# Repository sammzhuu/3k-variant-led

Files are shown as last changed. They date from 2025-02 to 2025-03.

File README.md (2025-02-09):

# 3k-variant-led
 a rehash of my scrapped 6k build now with 3k and leds 

if you want to build this project yourself, here are some useful guides: 
https://docs.google.com/document/d/1xsjb1sf3pxFw8bXC4gNhWsFhWNOthMoyz6RiJc1UtVI/edit?tab=t.0
https://www.youtube.com/watch?v=Ov2vdJQmaAw
https://www.masterzen.fr/2020/05/03/designing-a-keyboard-part-1/
https://wiki.ai03.com/books/pcb-design/page/pcb-guide-part-1---preparations

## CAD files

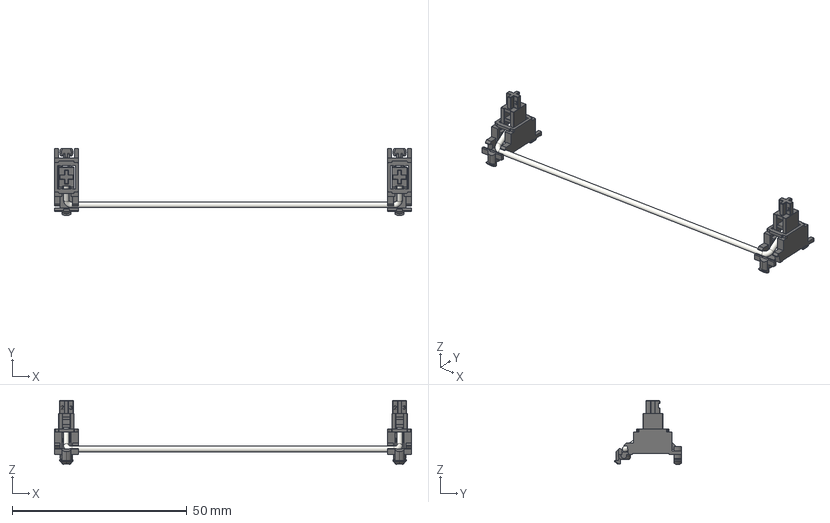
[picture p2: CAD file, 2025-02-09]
keyswitch-kicad-library/source_3d/Mounting_Keyboard_Stabilizer/Stabilizer_Cherry_MX_6u.FCStd
102.1 x 19.2 x 18.3 mm
Bar
Stabilizer_Key_
Stabilizer_Base_
Stabilizer_Key
Stabilizer_Base

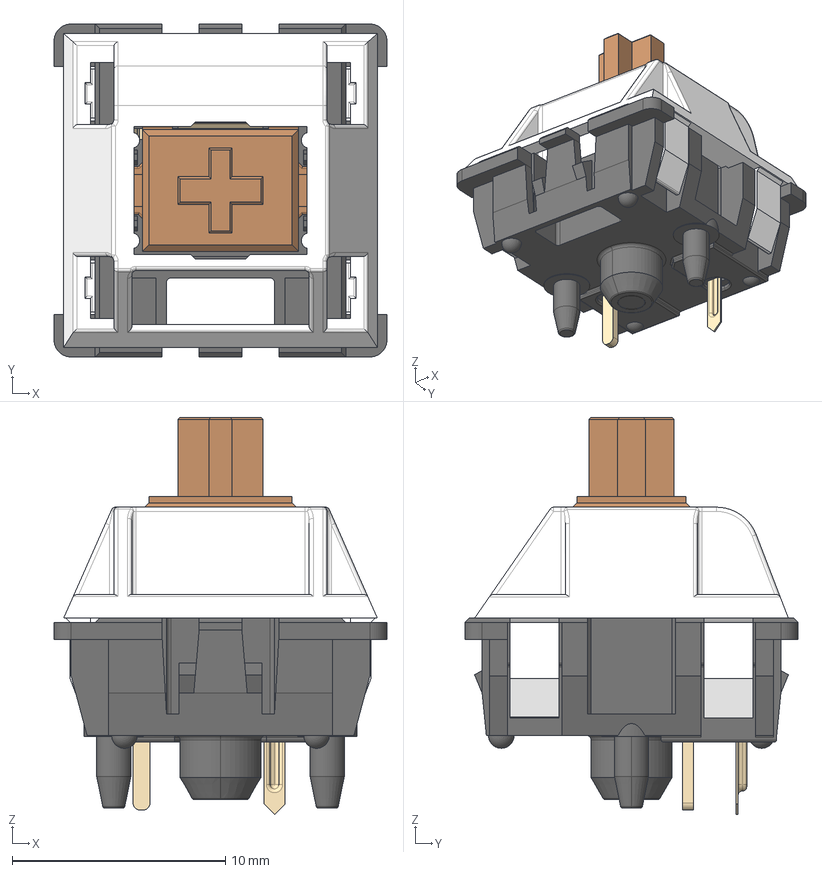
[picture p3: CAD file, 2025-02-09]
keyswitch-kicad-library/source_3d/Switch_Keyboard_Cherry_MX/SW_Cherry_MX_PCB.FCStd
15.6 x 15.6 x 18.6 mm
Lower_Housing
Upper_Housing
Stem
Pin_1
Pin_2
Spring
Clicker

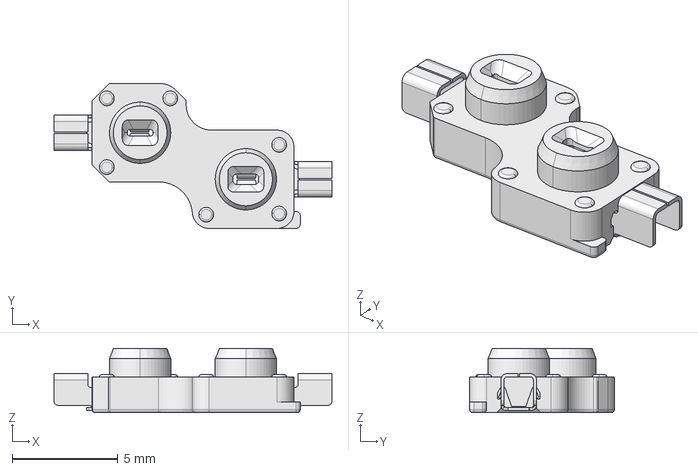
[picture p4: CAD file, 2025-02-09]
keyswitch-kicad-library/source_3d/Switch_Keyboard_Kailh/SW_Hotswap_Kailh_Choc_v1.FCStd
13.2 x 6.85 x 3.05 mm

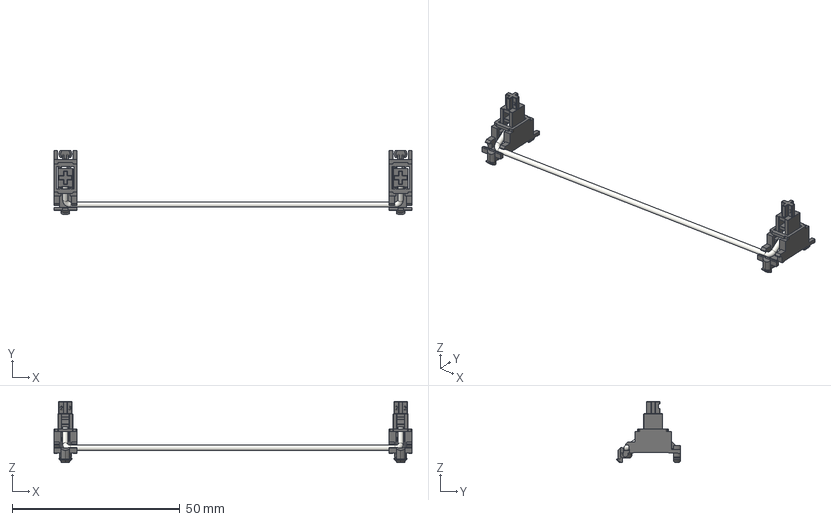
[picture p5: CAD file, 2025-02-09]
keyswitch-kicad-library/source_3d/Mounting_Keyboard_Stabilizer/Stabilizer_Cherry_MX_6.25u.FCStd
106.8 x 19.2 x 18.3 mm
Bar
Stabilizer_Key_
Stabilizer_Base_
Stabilizer_Key
Stabilizer_Base

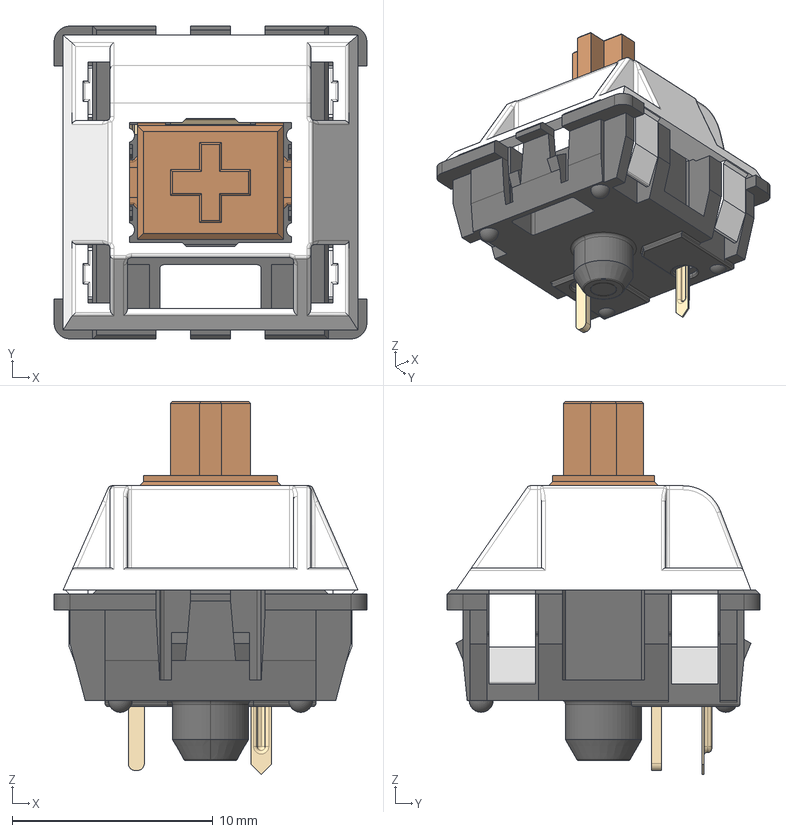
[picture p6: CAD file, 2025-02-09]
keyswitch-kicad-library/source_3d/Switch_Keyboard_Cherry_MX/SW_Cherry_MX_Plate.FCStd
15.6 x 15.6 x 18.6 mm
Lower_Housing
Upper_Housing
Stem
Pin_1
Pin_2
Spring
Clicker

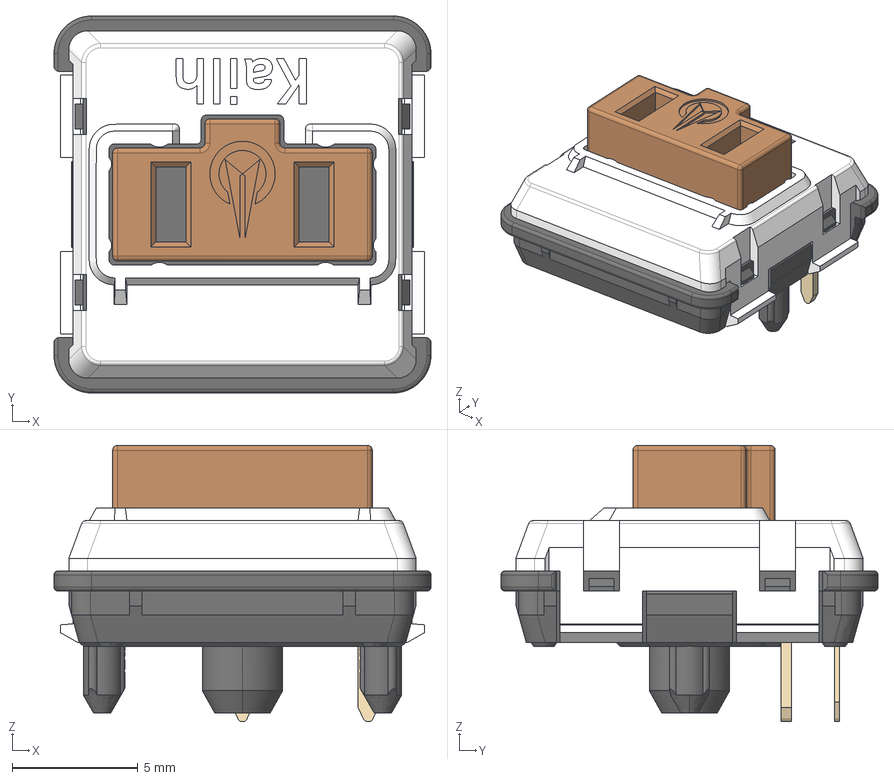
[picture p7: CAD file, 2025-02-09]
keyswitch-kicad-library/source_3d/Switch_Keyboard_Kailh/SW_Kailh_Choc_V1.FCStd
15.0 x 15.0 x 11.0 mm
Upper_Housing
Lower_Housing
Stem
Pin_2
Pin_1

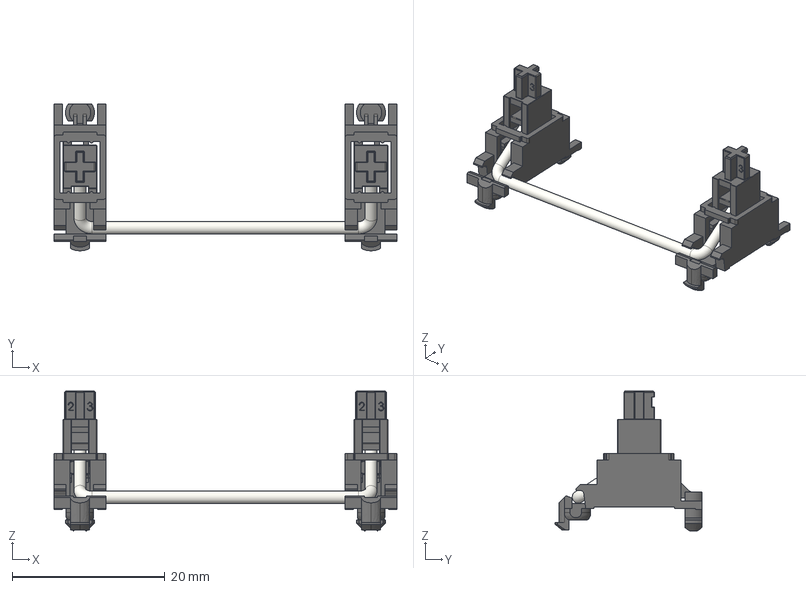
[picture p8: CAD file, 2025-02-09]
keyswitch-kicad-library/source_3d/Mounting_Keyboard_Stabilizer/Stabilizer_Cherry_MX_3u.FCStd
44.9 x 19.2 x 18.3 mm
Bar
Stabilizer_Key_
Stabilizer_Base_
Stabilizer_Key
Stabilizer_Base

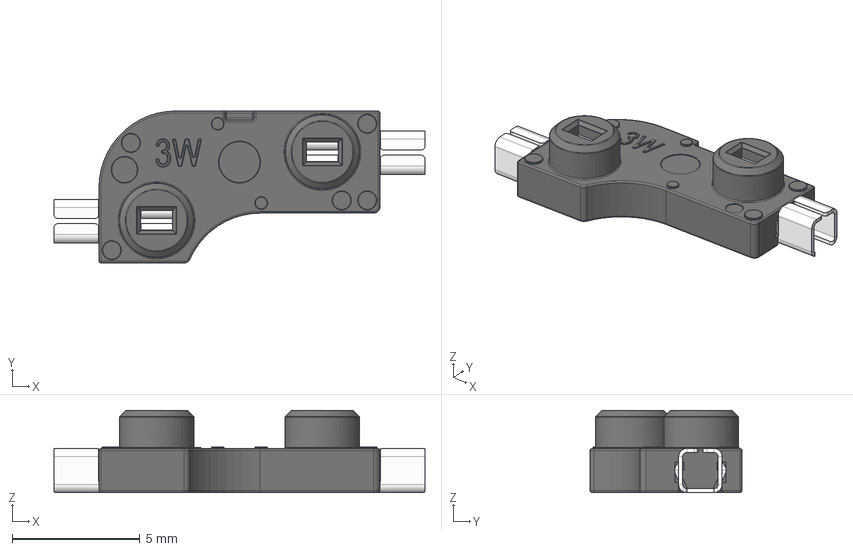
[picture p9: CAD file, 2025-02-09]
keyswitch-kicad-library/source_3d/Switch_Keyboard_Kailh/SW_Hotswap_Kailh.FCStd
14.5 x 5.95 x 3.22 mm
Pin_1
Pin_2
Plastic

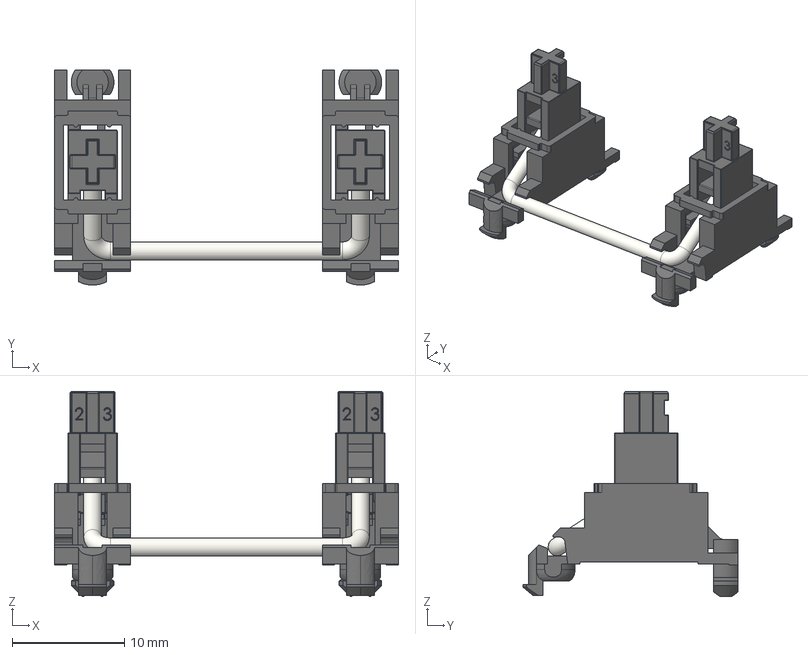
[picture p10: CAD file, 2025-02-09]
keyswitch-kicad-library/source_3d/Mounting_Keyboard_Stabilizer/Stabilizer_Cherry_MX_2u.FCStd
30.7 x 19.2 x 18.3 mm
Bar
Stabilizer_Key_
Stabilizer_Base_
Stabilizer_Key
Stabilizer_Base

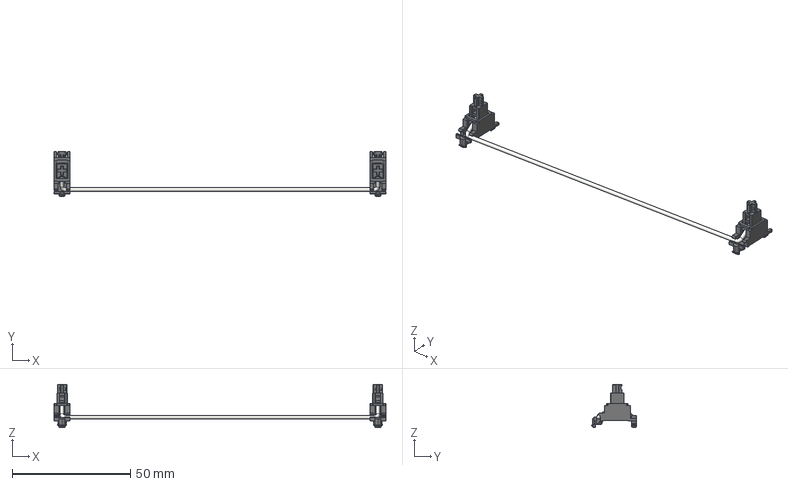
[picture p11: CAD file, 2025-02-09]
keyswitch-kicad-library/source_3d/Mounting_Keyboard_Stabilizer/Stabilizer_Cherry_MX_8u.FCStd
140.1 x 19.2 x 18.3 mm
Bar
Stabilizer_Key_
Stabilizer_Base_
Stabilizer_Key
Stabilizer_Base

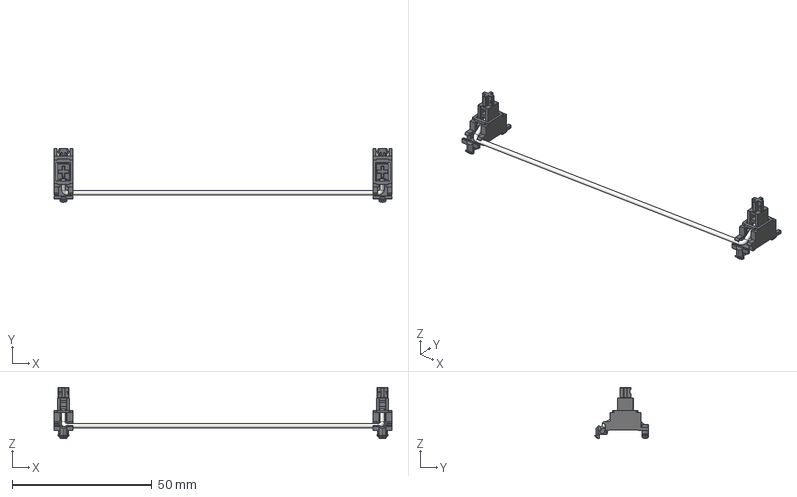
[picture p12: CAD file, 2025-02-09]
keyswitch-kicad-library/source_3d/Mounting_Keyboard_Stabilizer/Stabilizer_Cherry_MX_7u.FCStd
121.1 x 19.2 x 18.3 mm
Bar
Stabilizer_Key_
Stabilizer_Base_
Stabilizer_Key
Stabilizer_Base

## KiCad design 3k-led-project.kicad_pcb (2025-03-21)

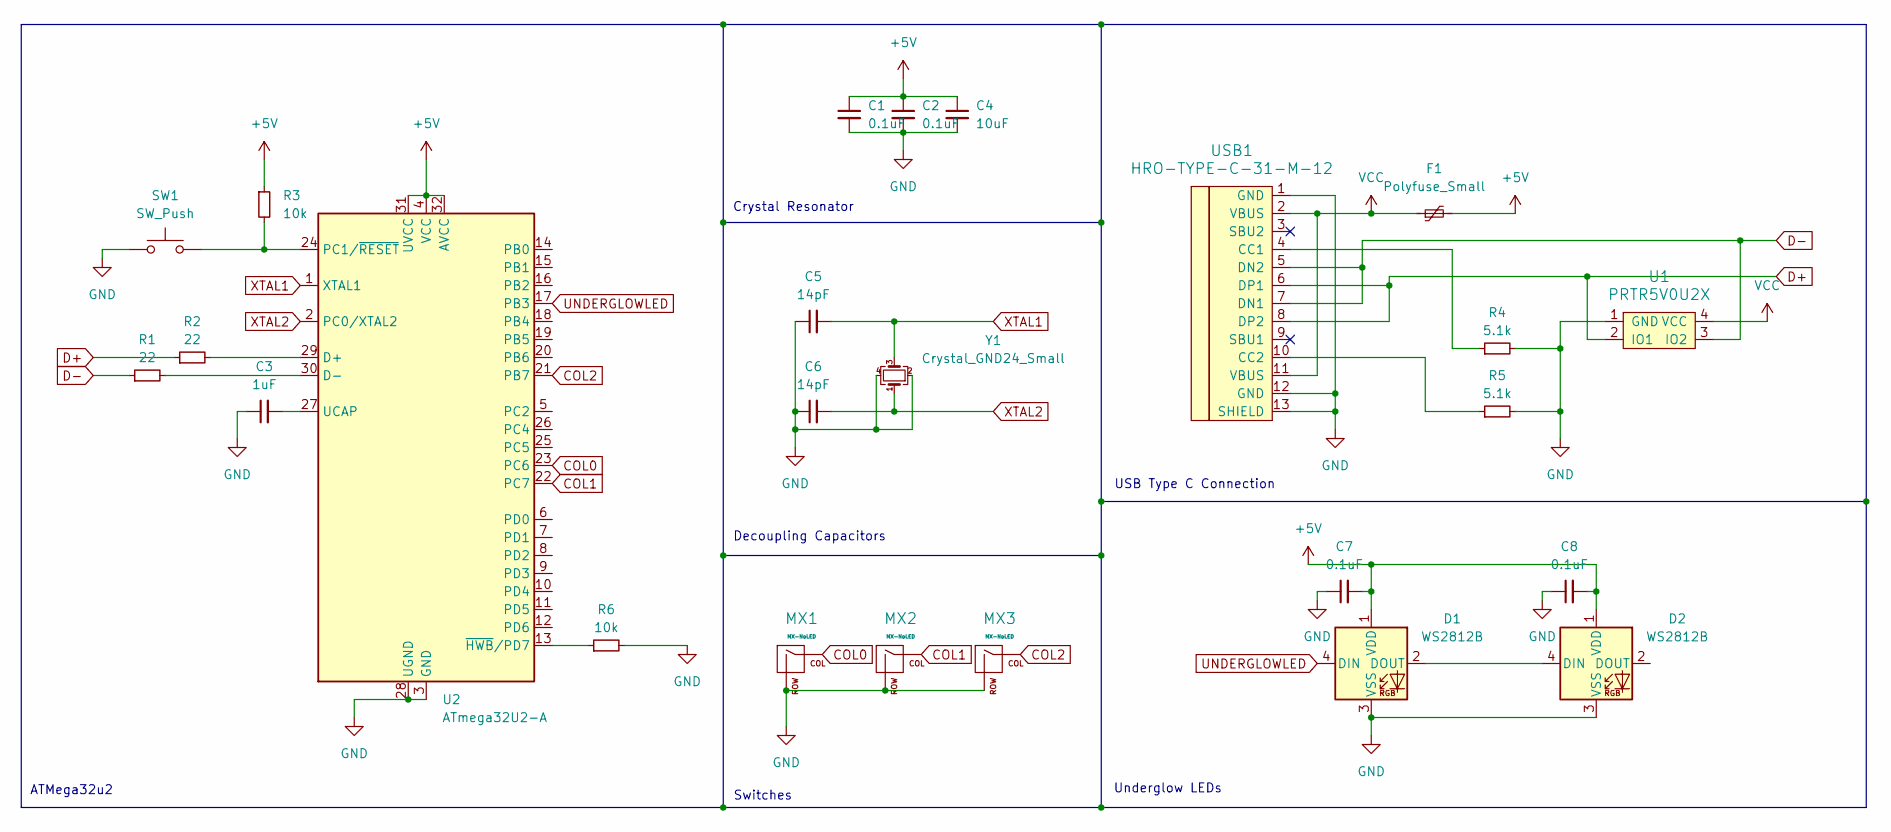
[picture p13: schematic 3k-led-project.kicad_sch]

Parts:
C1, C2, C7, C8: 0.1uF; C_0805_2012Metric_Pad1.18x1.45mm_HandSolder
C3: 1uF; C_0805_2012Metric_Pad1.18x1.45mm_HandSolder
C4: 10uF; C_0805_2012Metric_Pad1.18x1.45mm_HandSolder
C5, C6: 14pF; C_0805_2012Metric_Pad1.18x1.45mm_HandSolder
D1, D2: WS2812B; LED_WS2812B_PLCC4_5.0x5.0mm_P3.2mm
F1: Polyfuse_Small; Fuse_1206_3216Metric_Pad1.42x1.75mm_HandSolder
MX1, MX2, MX3: MX-NoLED; MXOnly-1U-Hotswap
R1, R2: 22; R_0805_2012Metric_Pad1.20x1.40mm_HandSolder
R3, R6: 10k; R_0805_2012Metric_Pad1.20x1.40mm_HandSolder
R4, R5: 5.1k; R_0805_2012Metric_Pad1.20x1.40mm_HandSolder
SW1: SW_Push; SKQGADE010
U1: PRTR5V0U2X; SOT143B
U2: ATmega32U2-A; TQFP-32_7x7mm_P0.8mm
USB1: HRO-TYPE-C-31-M-12; HRO-TYPE-C-31-M-12-HandSoldering
Y1: Crystal_GND24_Small; Crystal_SMD_3225-4Pin_3.2x2.5mm_HandSoldering

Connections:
+5V: C1.1, C2.1, C4.1, C7.2, C8.2, D1.1 (VDD), D2.1 (VDD), F1.2, R3.1, U2.4 (VCC), U2.31 (UVCC), U2.32 (AVCC)
COL0: MX1.1 (COL), U2.23 (PC6)
COL1: MX2.1 (COL), U2.22 (PC7)
COL2: MX3.1 (COL), U2.21 (PB7)
D+: R2.1, U1.2 (IO1), USB1.6 (DP1), USB1.8 (DP2)
D-: R1.1, U1.3 (IO2), USB1.5 (DN2), USB1.7 (DN1)
GND: C1.2, C2.2, C3.1, C4.2, C5.1, C6.1, C7.1, C8.1, D1.3 (VSS), D2.3 (VSS), MX1.2 (ROW), MX2.2 (ROW), MX3.2 (ROW), R4.2, R5.2, R6.2, SW1.1, U1.1 (GND), U2.3 (GND), U2.28 (UGND), USB1.1 (GND), USB1.12 (GND), USB1.13 (SHIELD), Y1.2, Y1.4
unnamed: D1.2 (DOUT), D2.4 (DIN)
unnamed: R2.2, U2.29 (D+)
unnamed: R1.2, U2.30 (D-)
unnamed: R3.2, SW1.2, U2.24 (PC1/~RESET)
unnamed: C3.2, U2.27 (UCAP)
unnamed: R6.1, U2.13 (~HWB/PD7)
unnamed: R4.1, USB1.4 (CC1)
unnamed: R5.1, USB1.10 (CC2)
UNDERGLOWLED: D1.4 (DIN), U2.17 (PB3)
VCC: F1.1, U1.4 (VCC), USB1.2 (VBUS), USB1.11 (VBUS)
XTAL1: C5.2, U2.1 (XTAL1), Y1.3
XTAL2: C6.2, U2.2 (PC0/XTAL2), Y1.1

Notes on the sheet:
Underglow LEDs
Crystal Resonator
Decoupling Capacitors
USB Type C Connection
Switches
ATMega32u2

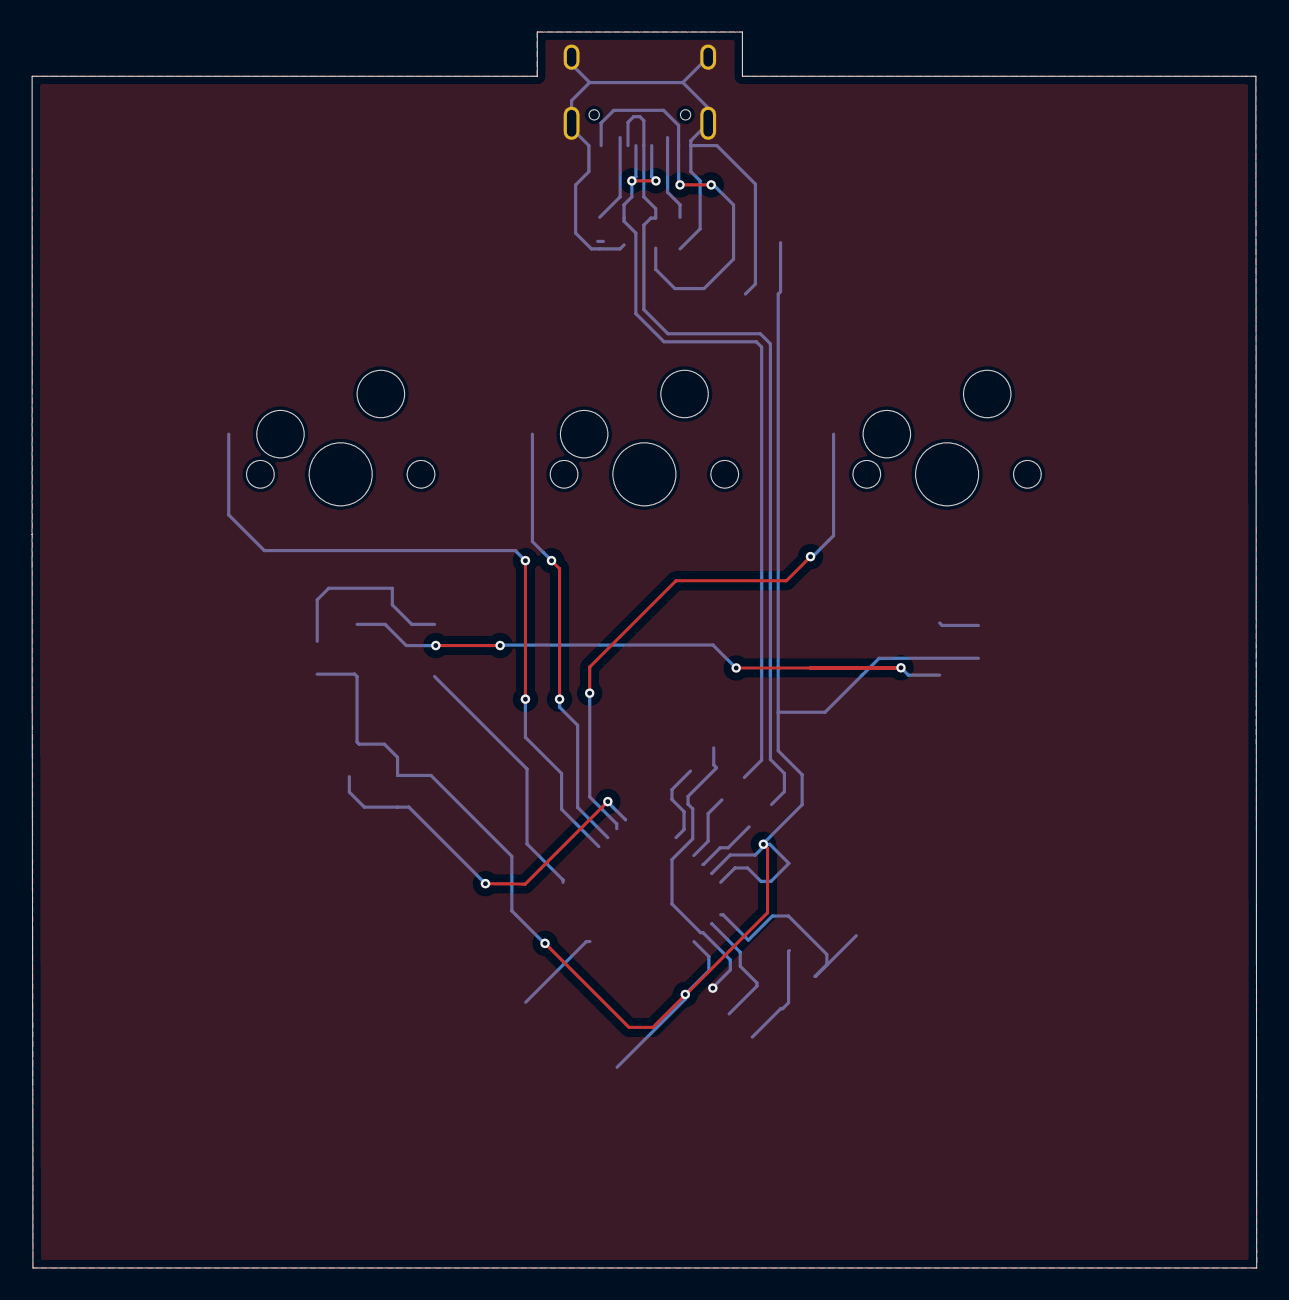
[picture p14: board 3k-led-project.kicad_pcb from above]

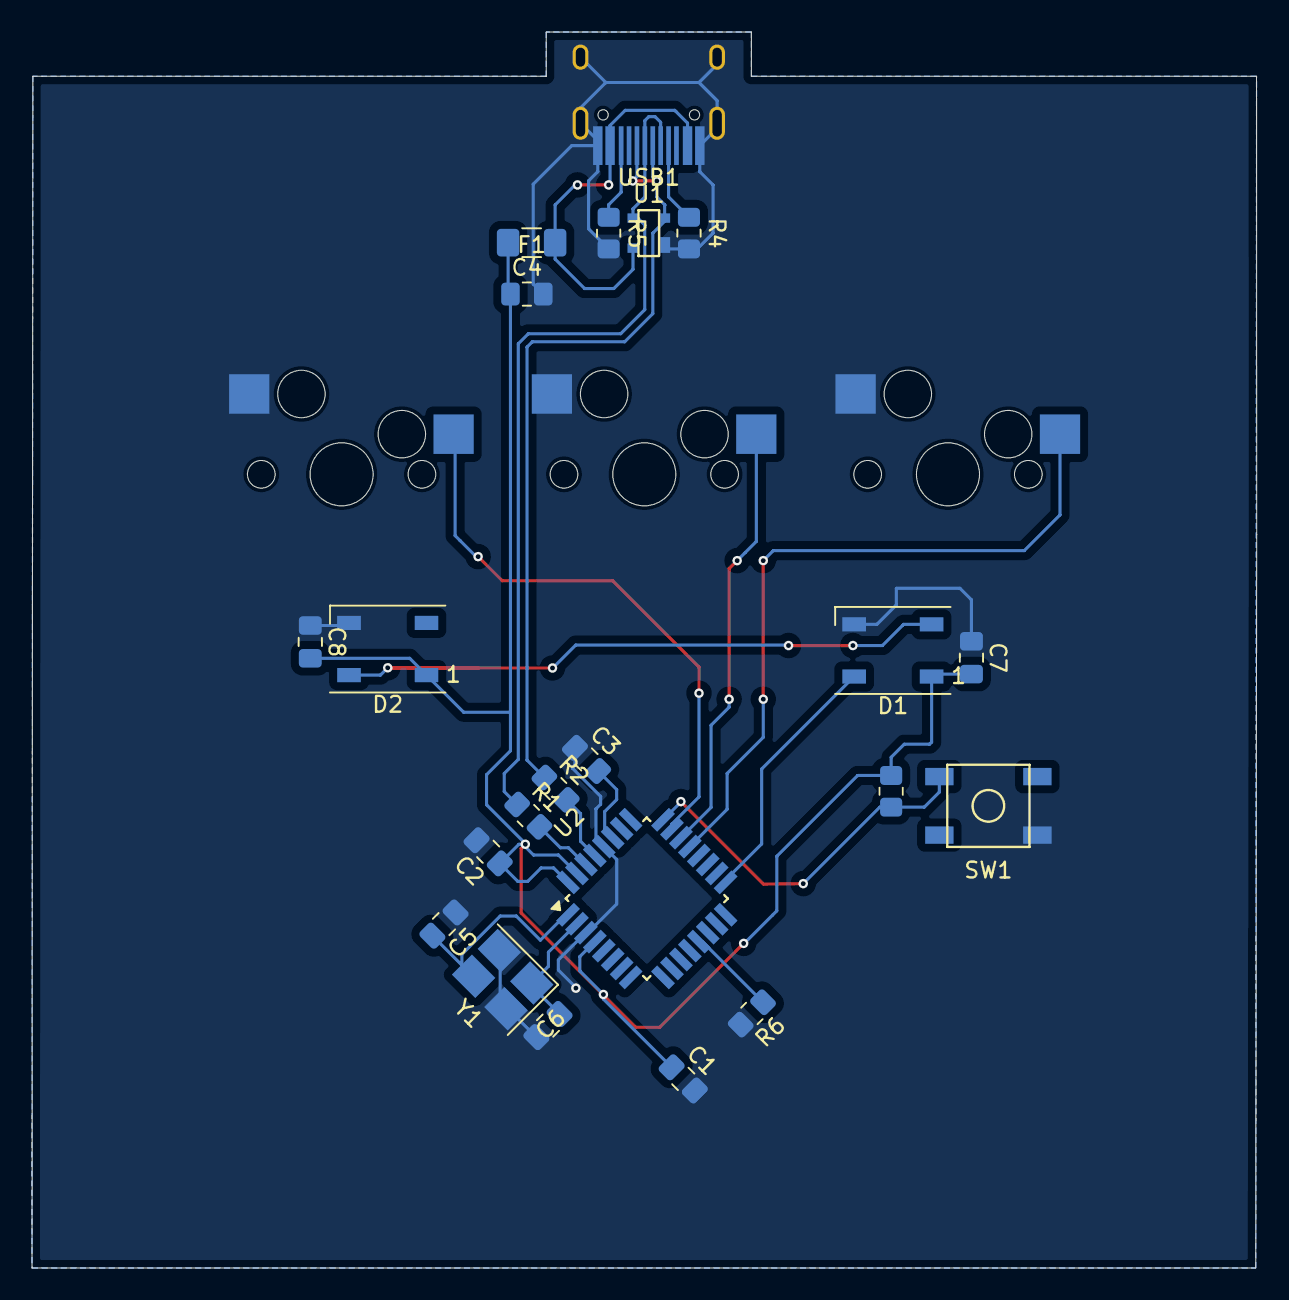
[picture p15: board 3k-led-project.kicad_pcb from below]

Board: 2 copper layers, 77.5 x 78.2 mm, 25 parts (22 on the bottom side), 19 nets.

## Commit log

2025-02-09 more submodules
    [SW_Cherry_MX_PCB.FCStd, SW_Cherry_MX_Plate.FCStd, SW_Hotswap_Kailh.FCStd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]
2025-02-09 finished schematic
    [3k-led-project.kicad_sch]
2025-02-09 barfed the components into the pcb and updated schematic
    [3k-led-project.kicad_pcb, 3k-led-project.kicad_sch]
